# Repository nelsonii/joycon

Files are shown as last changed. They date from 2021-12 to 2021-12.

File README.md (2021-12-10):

# joycon
Custom Cases for JoyCon Style Analog Joysticks

Print the flat sides down. No supports or rafts required. I printed Prusa Medium at 20% infill using Simplify3D.

If you are just printing the STLs, you'll want to flip the Y 180 degrees for the _TOP. 

Model uses two 1.6*4 MM screws to hold the joystick to the case. 
Currently set for 2.5 MM screw to mount the breakout board. -- SEE BELOW, now using M3
Case holds together with 2.5 MM screws also. -- SEE BELOW, now using M3

You can adjust the OpenSCAD model for different screw dimensions. Key stuff I put as variables.

At the least, you can use the OpenSCAD to grab the measurements for the joystick, stick mounts, Arduino Pro Micro Mounts, etc. These are very fiddly numbers. Save yourself some time. :-)

---

2021-12-08 : Posted revision 1H. Updated model for more common screw sizes. You still need M1.6*4 (or glue) to hold the joystick in place, but the breakout and case are now set for M3 screws (M3*12 best for case). M3*8 or shorter for breakout board. *Six or *four would be ideal.

---

2021-12-09 : Posted "PackOfGumStyle" -- which is an enlongated (80mm) version. Slightly (2mm) less height.
2021-12-10 : Updated PackOfGumStyle to make deeper screw holes for case closure (wasn't fitting 12mm screws).

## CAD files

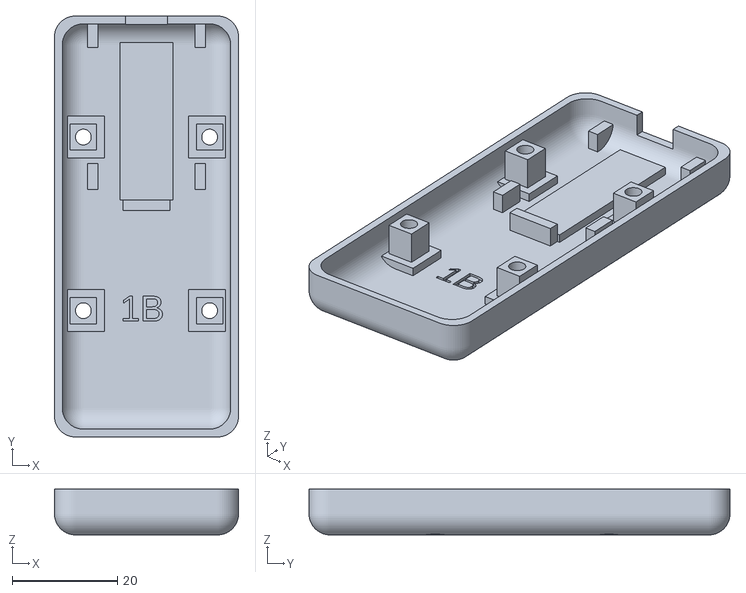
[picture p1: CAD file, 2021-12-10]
JoyconForXBAC_PackOfGumStyle_v1B_BOT.stl
35.0 x 80.0 x 8.71

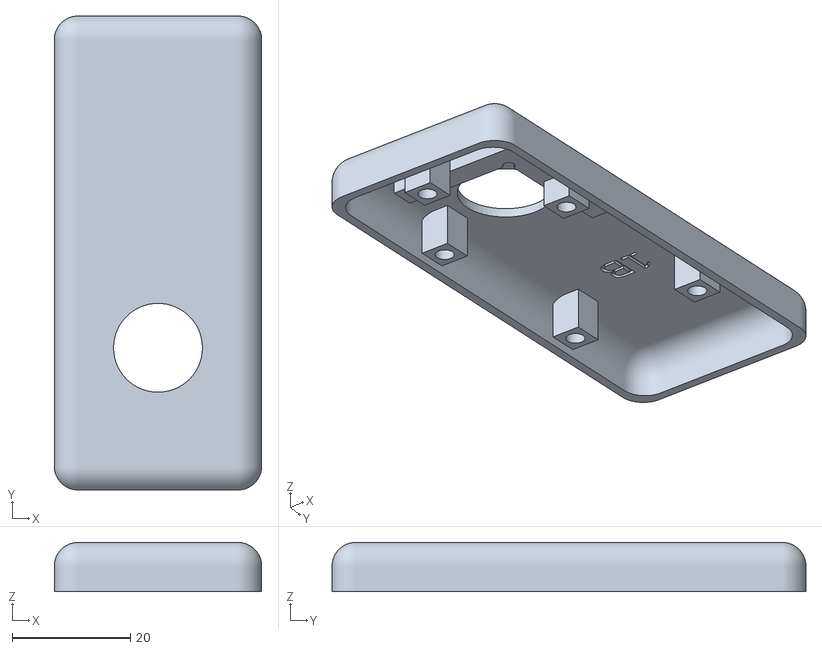
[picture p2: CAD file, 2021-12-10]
JoyconForXBAC_PackOfGumStyle_v1B_TOP.stl
35.0 x 80.0 x 8.31

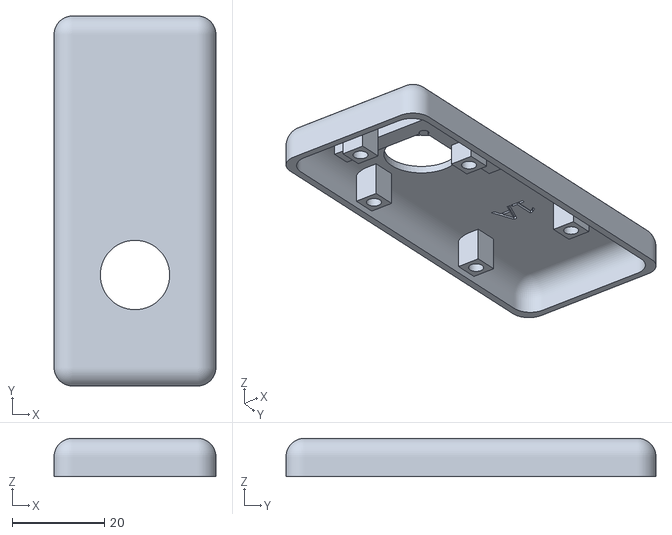
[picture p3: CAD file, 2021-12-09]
JoyconForXBAC_PackOfGumStyle_v1A_TOP.stl
35.0 x 80.0 x 8.31

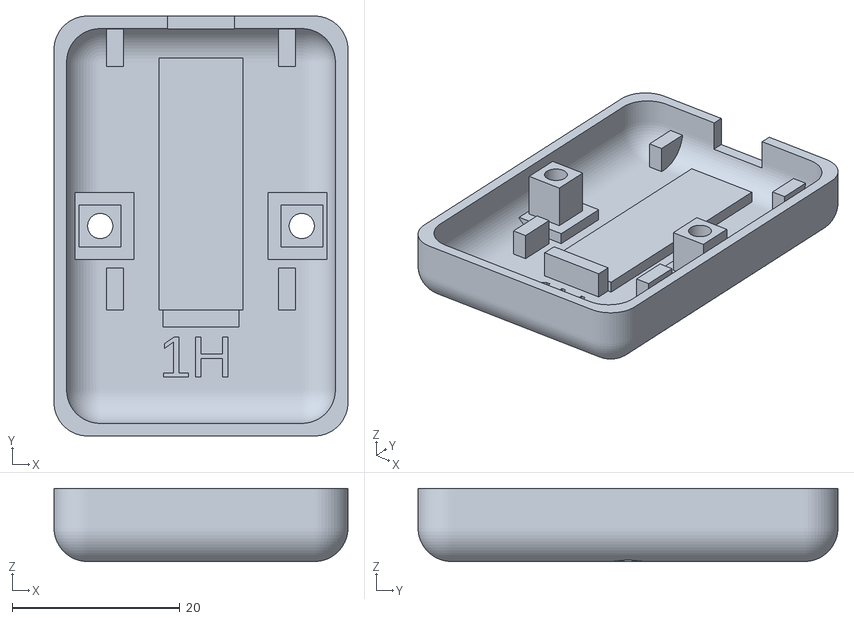
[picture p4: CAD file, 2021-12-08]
JoyconForXBAC_v1H_BOT.stl
35.0 x 50.0 x 8.71

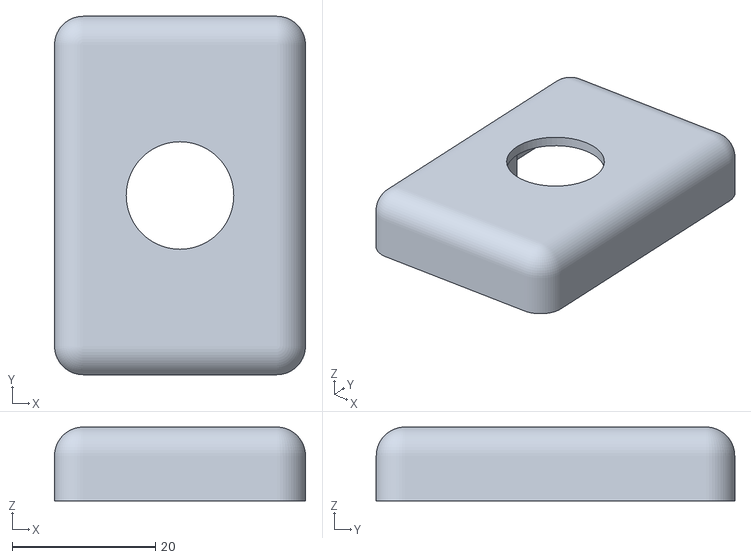
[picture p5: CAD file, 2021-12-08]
JoyconForXBAC_v1H_TOP.stl
35.0 x 50.0 x 10.3

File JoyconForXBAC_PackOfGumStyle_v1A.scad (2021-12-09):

include <BOSL/constants.scad>
use <BOSL/shapes.scad>

//JoyConForXBAC_PackOfGumStyle

fileVersion = "1A";

caseWidthX = 35;
caseDepthY = 80;
caseHeightZ = 18;
wallThickness = 3;
overlap = 1; // overlap ensures that subtractions go beyond the edges

stickScrewDiameter = 1.6; // M1.6 screw for attaching stick to case
breakoutScrewDiameter = 3; // M3 Screw (any head type)

caseScrewDiameter = 3; // M3 
caseScrewHeight = 12; // M3-12 mushroom head hex screw
caseScrewHeadDiameter = 5.25; // M3
caseScrewHeadHeight = 1.5; // M3 

emboss = true; // optional labels on case (inside and out)
includeCaseMounts = true; 
includeComponents = false; // optional component models, usually not included in print

  
$fn=60; //circle smoothness
  
difference(){
  union() {
    difference(){
      
      //base
      //rounded cuboid is from the BOSL library
      //I'm using p1 setting to zero bottom (z). X/Y are centered on 0,0,0
      color("steelblue")
      cuboid([caseWidthX,caseDepthY,caseHeightZ], fillet=4, 
       p1=[-(caseWidthX/2), -(caseDepthY/2), 0]);
      
      //subtract out the inner cuboid
      cuboid([caseWidthX-wallThickness,caseDepthY-wallThickness,caseHeightZ-wallThickness], fillet=4, 
       p1=[-((caseWidthX-wallThickness)/2), -((caseDepthY-wallThickness)/2), (wallThickness/2)]);
      
      //subtract out the hole for the joystick
      color("pink")
       translate([0,-16,(caseHeightZ-wallThickness-overlap)])
        cylinder( h=10 , d=15, center=true); //can't be less than 14.75, otherwise cap of stick won't fit.
      
      if (emboss) {
        //emboss version on inside case (bottom)
        color("whitesmoke")
         translate([-5, -18, 1])
          linear_extrude(2)
           text(fileVersion, size=5);
        //emboss version on inside case (top)
        mirror([1,0,0]) // since this is "upside down, inside" we mirror the text
         color ("whitesmoke")
          translate([-5,11, caseHeightZ-wallThickness])
           linear_extrude(2)
            text(fileVersion, size=5);
        /*
        //emboss port info on outside of case
        color("whitesmoke")
         translate([-5, 25, caseHeightZ - 1]) 
          linear_extrude(2)
           text("USB", size=5);
        */
      }
    }//difference (base)

    //riser for micro pro board
    color("purple")
     translate([-5,5,0])
      cube([10, 30, 3]);
   
    //bumper for micro pro board -- endstop
    color("violet")
     translate([-4.5, 3, 0])  
      cube([9, 2, 5]);
    //bumpers for micro pro board -- lower side
    color("violet")
     translate([-11.25, 7, 0]) 
      cube([2,5,5]);
    color("violet")
     translate([9.25, 7, 0]) 
      cube([2,5,5]);
    //bumpers for micro pro board -- upper side
    color("violet")
     translate([-11.25, 34, 1.5]) 
      cube([2,5,3.5]);
    color("violet")
     translate([9.25, 34, 1.5]) 
      cube([2,5,3.5]);

    /*
    //orientation pin (toward front -- +y)
    //include this early on to keep track of which way is up. :-)
    color("olivedrab")
     translate([0,18,caseHeightZ-wallThickness+1])
      cylinder(h=1, d=2, center=true);
    */

    //mounting bars for joystick
    color("lime") //horz
     translate([-11, -30, caseHeightZ-wallThickness-1])
      cube([23, 4, 4]);
    color("lime") //vert
     translate([8.5, -30, caseHeightZ-wallThickness-1])
      cube([4, 25, 4]);
      
    //mount for joystick breakout board
    color("greenyellow")
     translate([-5, -35, caseHeightZ-wallThickness-6])
      cube([5,5,9]);

    if (includeCaseMounts) {
      //case screw mounts -- near joystick
      color("gold")
       translate([-12-2.5, -18.5, 1])
        cube([5,5,caseHeightZ-2]);
      color("gold")
       translate([+12-2.5, -18.5, 1])
        cube([5,5,caseHeightZ-2]);
      //case screw mount countersink strengthener
      color("PeachPuff")
       translate([-12-3, -20, 1])
        cube([7,8,wallThickness-1]);
      color("PeachPuff")
       translate([+12-4, -20, 1])
        cube([7,8,wallThickness-1]);
      //case screw mounts -- near mcu --------------------------------
      color("gold")
       translate([-12-2.5, +14.5, 1])
        cube([5,5,caseHeightZ-2]);
      color("gold")
       translate([+12-2.5, +14.5, 1])
        cube([5,5,caseHeightZ-2]);
      //case screw mount countersink strengthener
      color("PeachPuff")
       translate([-12-3, +13, 1])
        cube([7,8,wallThickness-1]);
      color("PeachPuff")
       translate([+12-4, +13, 1])
        cube([7,8,wallThickness-1]);
    }//includeCaseMounts

    if (includeComponents) {

    }//includeComponents
    
  }//union
  
  // Start of Difference stuff

  //USB Micro cable outlet
  color("coral")
   translate([-4.0, 35, 4.75])
    cube([8, (wallThickness*2), 4]);

  //screw holes for mounting joystick (inside upper lid)
  color("orange") //horz
   translate([-6.625, -27.5, caseHeightZ-wallThickness-4.5])
    cylinder(h=6, d=stickScrewDiameter);
  color("orange") //vert
   translate([9.75, -8.75, caseHeightZ-wallThickness-4.5])
    cylinder(h=6, d=stickScrewDiameter);
  
  //screw hole for mounting joystick breakout board (inside upper lid)
  color("orange")
   translate([-2.5, -32.5, caseHeightZ-wallThickness-7])
    cylinder(h=8, d=breakoutScrewDiameter);

  //carve out inside intersection of joystick mounting bars
  color("coral")
   translate([8.25, -25.75, caseHeightZ-wallThickness-4.5])
    cylinder(h=6, d=2);


  if (includeCaseMounts) {
    //screw hole for case (goes through bottom of case) -- near joystick
    color("tomato")
     translate([-12, -16, -overlap])
      cylinder(h=caseHeightZ-wallThickness-2, d=caseScrewDiameter);
    color("tomato")
     translate([+12, -16, -overlap])
      cylinder(h=caseHeightZ-wallThickness-2, d=caseScrewDiameter);
    //countersink
    color("darkorange")
     translate([-12, -16, -overlap])
      cylinder(h=caseScrewHeadHeight+overlap, d=caseScrewHeadDiameter);
    color("darkorange")
     translate([+12, -16, -overlap])  
      cylinder(h=caseScrewHeadHeight+overlap, d=caseScrewHeadDiameter);
    //screw hole for case (goes through bottom of case) -- near mcu
    color("tomato")
     translate([-12, +17, -overlap])
      cylinder(h=caseHeightZ-wallThickness-2, d=caseScrewDiameter);
    color("tomato")
     translate([+12, +17, -overlap])
      cylinder(h=caseHeightZ-wallThickness-2, d=caseScrewDiameter);
    //countersink
    color("darkorange")
     translate([-12, +17, -overlap])
      cylinder(h=caseScrewHeadHeight+overlap, d=caseScrewHeadDiameter);
    color("darkorange")
     translate([+12, +17, -overlap])  
      cylinder(h=caseScrewHeadHeight+overlap, d=caseScrewHeadDiameter);
  }//includeCaseMounts
 
  //-------------------------------------------------------------------------------------------------------

  splitAtZ=8.7; //size this so the hole for the usb is all on the bottom part (easier printing)
  
  //remove the top for split
  //color("crimson")  translate([-((caseWidthX+overlap)/2),-((caseDepthY+overlap)/2),splitAtZ])  cube([caseWidthX+overlap, caseDepthY+overlap, caseHeightZ+overlap]);
  // ******* OR ******
  //Remove everything but the top
  color("crimson") translate([-((caseWidthX+overlap)/2),-((caseDepthY+overlap)/2),splitAtZ-caseHeightZ])  cube([caseWidthX+overlap, caseDepthY+overlap, caseHeightZ+overlap]);

  //-------------------------------------------------------------------------------------------------------
  
  
}//difference
  

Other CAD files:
JoyconForXBAC_PackOfGumStyle_v1A_BOT.stl
JoyconForXBAC_v1p7_BOT.stl
JoyconForXBAC_v1p7_TOP.stl
JoyconForXBAC_PackOfGumStyle_v1B.scad
JoyconForXBAC_v1H.scad
JoyconForXBAC_v1p7.scad

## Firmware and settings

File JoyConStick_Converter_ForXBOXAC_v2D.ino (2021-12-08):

//JoyConStick_Converter_ForXBOXAC_v2D

//=================================================================================

#include "Joystick.h"

//=================================================================================

Joystick_ Joystick(JOYSTICK_DEFAULT_REPORT_ID, 
  JOYSTICK_TYPE_JOYSTICK, 1, 0,
  true, true, false, false, false, false,
  false, false, false, false, false);

// constructor: use default id, it's a joystick, there is one button,
//              there are no hat buttons, there is an X and Y analog
//              and no other controls.

//=================================================================================

const boolean debug = false; // if true, output info to serial monitor.
const boolean graph = false; // if true, output data for plotter/graph viewing.

//=================================================================================

// Joystick pins
#define VERT_PIN    A1 // physical pin 19 // AKA the "Y" -- dependent on how thumbstick is oriented
#define HORZ_PIN    A2 // physical pin 20 // AKA the "X" -- dependent on how thumbstick is oriented
#define BUTTON_PIN  A3 // physical pin 21 // Pushbutton of the thumbstick

// Old-school Atari digital up/down/left/right buttons
// Not currently used, but wired in my test setup
const int DIG_UP = 4;
const int DIG_DN = 5;
const int DIG_LT = 6;
const int DIG_RT = 7;  

// Mapping to XBOX Adaptive Controller
// X and Y will auto map to Axis 0/1 or 2/3 depending on which side you plug
// the joystick into (left=0/1 or right=2/3). The pushbutton on the stick needs
// to be set & programmed depending on placement. 
// ********* TODO: Some sort of config on stick?
// 10=Left Stick Press, 11=Right Stick Press
int XBOX_AC_STICK_BUTTON = 10;

// Joystick variables - Button (with debounce)
int SEL, prevSEL = HIGH;
long lastDebounceTime = 0;
const int debounceDelay = 50;  //millis

//=================================================================================

// values from analog stick
long rawHorz, rawVert;
long mapHorz, mapVert;

// invert if needed
const bool invHorz = false;
const bool invVert = false;

//=================================================================================

// The XBOX Adapative Controller (XAC) likes joystick values from -127 to + 127
// adjust these min/max based on your upstream device. Same values for both X and Y.
const int joyMin = -127;
const int joyMax = +127;

//=================================================================================

// set the default min/max values.
// Determined during testing. These are for JoyCon Switch style joysticks.
// Adjust values based on what you actually get from the stick being used.

int minHorz=114;
int centeredHorz=485;
int maxHorz=866;

int minVert=114;
int centeredVert=489;
int maxVert=799;

//hard limits, to catch out-of-range readings
const int limitMinHorz=100;
const int limitMaxHorz=900;
const int limitMinVert=100;
const int limitMaxVert=900;

//=================================================================================


void setup() {

  // Startup the joystick object. 
  Joystick.begin(false); // false indicates that sendState method call required (so we do all changes at once).

  // I'm using Map below, but setting range Just In Case.
  // Also setting Axis to zero at startup.
  Joystick.setXAxisRange(joyMin, joyMax); Joystick.setXAxis(0);
  Joystick.setYAxisRange(joyMin, joyMax); Joystick.setYAxis(0);
  Joystick.sendState();

  // Set HORZ and VERT and BUTT pins (from joystick) to input
  pinMode(VERT_PIN, INPUT);
  pinMode(HORZ_PIN, INPUT);
  pinMode(BUTTON_PIN, INPUT_PULLUP);

  if (debug) { 
    Serial.begin(9600);
    Serial.println("JoyConStick_Converter_ForXBOXAC_v2p1");
  }

  // On startup, take some readings from the (hopefully) 
  // centered joystick to determine actual center for X and Y. 
  int iNumberOfSamples = 25;
  long lSampleSumHorz = 0;
  long lSampleSumVert = 0;
  for (int iSample = 1; iSample<=iNumberOfSamples; iSample++) {
    lSampleSumHorz += analogRead(HORZ_PIN); delay(10);
    lSampleSumVert += analogRead(VERT_PIN); delay(10);
  }
  centeredHorz=int(lSampleSumHorz/iNumberOfSamples);
  centeredVert=int(lSampleSumVert/iNumberOfSamples);

}//setup


//=================================================================================


void loop() {

  // ----------------------------------------------------

  // Check for button push - and debounce
  int reading = digitalRead(BUTTON_PIN);
  if (reading != prevSEL) {
     lastDebounceTime = millis();// reset timer
  }
  if (millis() - lastDebounceTime > debounceDelay) {
    if (reading != SEL) {
      SEL = reading;
      if (SEL == LOW) {Joystick.pressButton(XBOX_AC_STICK_BUTTON);}
      else {Joystick.releaseButton(XBOX_AC_STICK_BUTTON);}
    }
  }
  prevSEL = reading;

  // ----------------------------------------------------

  // Read analog values from input pins.
  rawHorz = analogRead(HORZ_PIN); delay(10);
  rawVert = analogRead(VERT_PIN); delay(10);

  // Toss out invalid ranges (out of limit). If out of range, set to centered value.
  if (rawHorz<limitMinHorz || rawHorz>limitMaxHorz) {rawHorz=centeredHorz;}
  if (rawVert<limitMinVert || rawVert>limitMaxVert) {rawVert=centeredVert;}
  
  // update the min/max during run, in case we see something outside of the normal
  if (rawHorz<minHorz) {minHorz=rawHorz;}
  if (rawHorz>maxHorz) {maxHorz=rawHorz;}
  if (rawVert<minVert) {minVert=rawVert;}
  if (rawVert>maxVert) {maxVert=rawVert;}

  // Map values to a range the upstread device likes
  mapHorz = map(rawHorz, minHorz, maxHorz, joyMin, joyMax);
  mapVert = map(rawVert, minVert, maxVert, joyMin, joyMax);

  // Clean up center position, the 5 and 15 are based on value seen during testing.
  if (abs(mapHorz)>0 && abs(mapHorz)<4) {mapHorz=0;}
  if (abs(mapVert)>0 && abs(mapVert)<14) {mapVert=0;}
  
  // Invert value if requested (if "up" should go "down" or "left" to "right")
  if (invHorz) {mapHorz = -mapHorz;}
  if (invVert) {mapVert = -mapVert;}

  // Send the values to the joystick object
  Joystick.setXAxis(mapHorz);
  Joystick.setYAxis(mapVert);

  // Send updated joystick state to HID upstream
  Joystick.sendState();

  // ----------------------------------------------------

  if (debug) {serialDebug();}

}//loop

//=================================================================================

void serialDebug() {
  
    if (!graph) {
      Serial.print("H: ");
      Serial.print(minHorz);
      Serial.print(" ");
      Serial.print(centeredHorz);
      Serial.print(" ");
      Serial.print(maxHorz);
      Serial.print(" ");
      Serial.print("V: ");
      Serial.print(minVert);
      Serial.print(" ");
      Serial.print(centeredVert);
      Serial.print(" ");
      Serial.print(maxVert);
      Serial.print(" ");
      Serial.print("Raw H/V: ");
      Serial.print(rawHorz);
      Serial.print(" ");
      Serial.print(rawVert);
      Serial.print(" ");
    }
    if (!graph) {Serial.print("Button: ");}
    //always graph/print button
    Serial.print(digitalRead(BUTTON_PIN));
    Serial.print(" ");
    if (!graph) {Serial.print("Map H/V: ");}
    //always graph/print mapped horz/vert
    Serial.print(mapHorz);
    if (invHorz) { Serial.print("i"); } // i indicates value was inverted 
    Serial.print(" ");
    Serial.print(mapVert);
    if (invVert) { Serial.print("i"); } // i indicates value was inverted
    Serial.print(" ");
    Serial.println();

}//serialDebug

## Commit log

2021-12-08 Add files via upload
    Updated model for more common screw sizes. You still need M1.6*4 (or glue) to hold the joystick in place, but the breakout and case are now set for M3 screws (M3*12 best for case).
    [JoyconForXBAC_v1H.scad, JoyconForXBAC_v1H_BOT.stl, JoyconForXBAC_v1H_TOP.stl]
2021-12-08 Update README.md
    Added notes on screw sizes.
2021-12-08 Add files via upload
    Arduino Code
2021-12-09 Add files via upload
    Pack of Gum Style (elongated)
    [JoyconForXBAC_PackOfGumStyle_v1A.scad, JoyconForXBAC_PackOfGumStyle_v1A_BOT.stl, JoyconForXBAC_PackOfGumStyle_v1A_TOP.stl]
2021-12-10 Add files via upload
    Updated to cut deeper holes in case.
    [JoyconForXBAC_PackOfGumStyle_v1B.scad, JoyconForXBAC_PackOfGumStyle_v1B_BOT.stl, JoyconForXBAC_PackOfGumStyle_v1B_TOP.stl]
